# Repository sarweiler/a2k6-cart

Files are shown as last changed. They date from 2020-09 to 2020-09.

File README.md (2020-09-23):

# A2k6 Cartridge

A cartridge PCB for the Atari 2600 for housing a 2732 EPROM and a 74LS04 hex inverter IC.

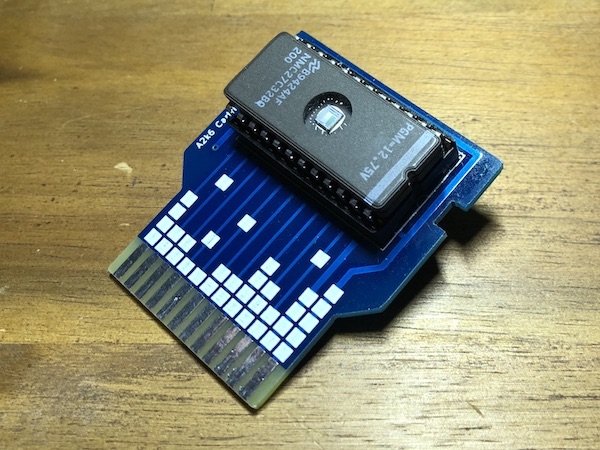
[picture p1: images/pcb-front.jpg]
a2k6 pcb front


More photos:
* [Back side with 74LS04](images/pcb-back.jpg)
* [Inserted in an original Atari cartridge case](images/pcb-case.jpg)

## Producing a PCB

Download the [a2k6-cart-gerbers.zip](https://github.com/sarweiler/a2k6-cart/releases/latest/download/a2k6-cart-gerbers.zip) file for the latest release, upload the zip archive to a PCB manufacturer of your choice, and order a PCB. Make sure to choose 1.6 mm for PCB thickness (for many manufacturers this is the default) and choose a color for the solder mask that you like.

## EPROMs

So far I could only test it with one EPROM model, the National Semiconductors NMC27C32BQ200, because it's the only one I have on hand. Others with similar pin outs may work, too. If you've successfully tested one, feel free to message me, and I'll keep a list here.

## Using the PCB

The PCB fits in a standard Atari 2600 game cartridge case ([tested with a Starmaster case](images/pcb-case.jpg)). In my tests, the EPROM *with* a socket unfortunately was just a bit too thick, so if you plan to put the PCB in a case, I think the EPROM must be soldered to the PCB.

On the PCB, the side with the square pattern (the side with the EPROM) is the "label" side and must face towards the back of the console when inserting it.



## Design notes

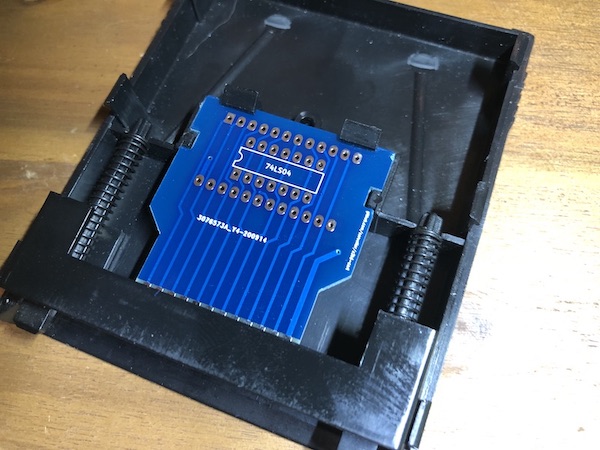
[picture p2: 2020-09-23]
images/pcb-case.jpg

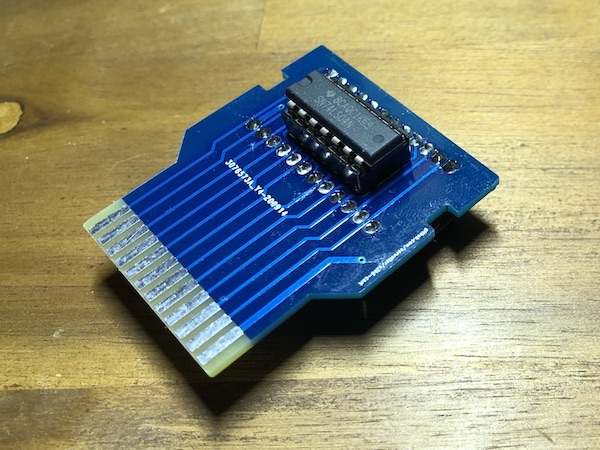
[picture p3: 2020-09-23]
images/pcb-back.jpg

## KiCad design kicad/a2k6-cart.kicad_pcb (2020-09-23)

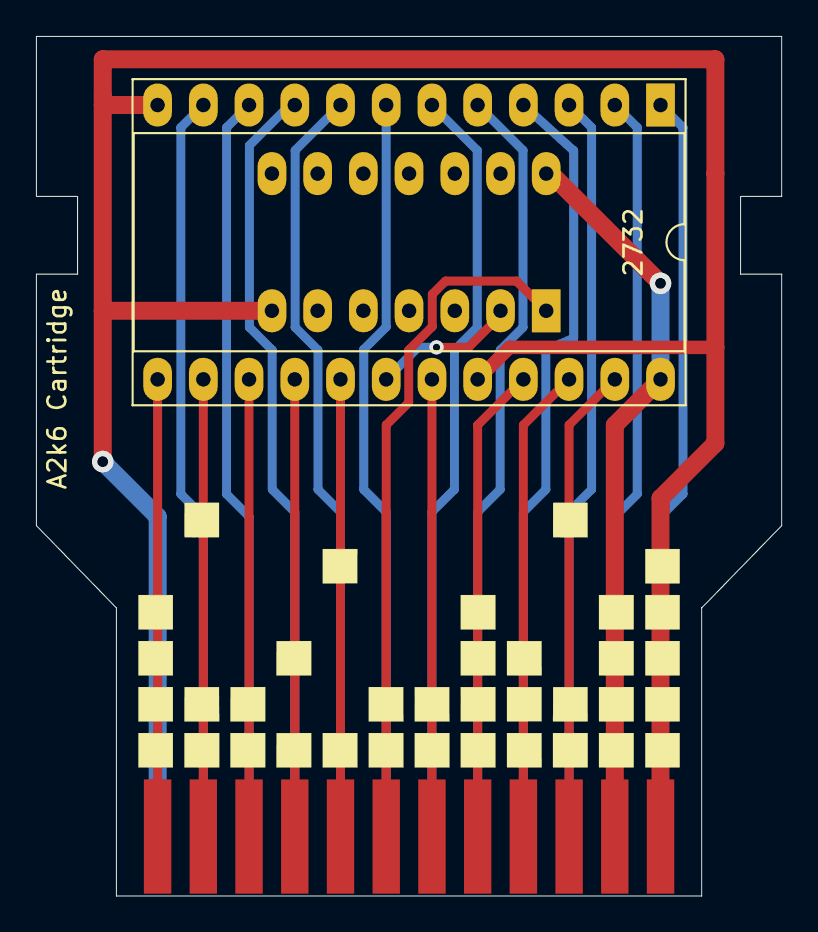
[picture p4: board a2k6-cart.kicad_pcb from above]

Board: 2 copper layers, 41.4 x 47.8 mm, 3 parts (1 on the bottom side), 24 nets.

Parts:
J1: 2600_Cartridge_Port
U1: 2732; DIP-24_W15.24mm_Socket_LongPads
U2: 74LS04; DIP-14_W7.62mm_LongPads

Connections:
+5V: J1.+5V, U1.24, U2.14
D0: J1.D0, U1.9
D1: J1.D1, U1.10
D2: J1.D2, U1.11
D3: J1.D3, U1.13
D4: J1.D4, U1.14
D5: J1.D5, U1.15
D6: J1.D6, U1.16
D7: J1.D7, U1.17
GND: J1.GND, J1.SGND, U1.12, U1.20, U2.7
unnamed: J1.A0, U1.8
unnamed: J1.A1, U1.7
unnamed: J1.A2, U1.6
unnamed: J1.A3, U1.5
unnamed: J1.A4, U1.4
unnamed: J1.A5, U1.3
unnamed: J1.A6, U1.2
unnamed: J1.A7, U1.1
unnamed: J1.A8, U1.23
unnamed: J1.A9, U1.22
unnamed: J1.A10, U1.19
unnamed: J1.A11, U1.21
unnamed: J1.A12, U2.1
unnamed: U1.18, U2.2

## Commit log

2020-09-23 link case image
2020-09-23 take off 0.4 mm from the sides of the pcb
    [a2k6-cart.kicad_pcb]
2020-09-23 remove file
    [a2k6-cart.kicad_pcb]
2020-09-23 add gerber files
    [a2k6-cart-B_Cu.gbr, a2k6-cart-B_Mask.gbr, a2k6-cart-B_Paste.gbr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]
